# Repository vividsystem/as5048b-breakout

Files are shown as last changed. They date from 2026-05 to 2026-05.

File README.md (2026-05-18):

# AS5048B Breakout Board


> [!NOTE]
> This is a breakout for the AS5048B not AS5048A board i.e. this is a breakout for the I²C version.

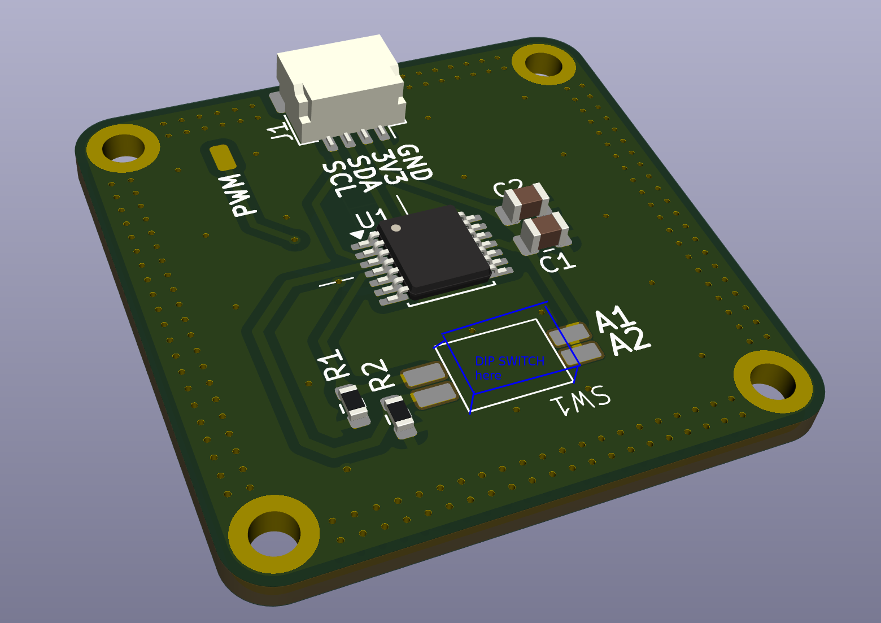
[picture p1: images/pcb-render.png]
PCB Render


## Specs & Features 
- 14bit resolution -> 16384 positions per revolution
- I²C High Speed at 3.4MHz clock frequency
- easy hand-assembly
- JST SM04B-SRSS (SH series) connector for easy connections
(SparkFun Qwiic/Adafruit STEMMA QT/Arduino Modulino compatible)

## Usage
### Choosing the correct magnet
* 6-8mm diameter
* \>= 2.5mm height
* diametric

### Magnet Placement
* 0.5mm to 2.5mm above IC
* magnet and board share same center (displacement of up to 0.25mm ok)

more details [here](https://look.ams-osram.com/m/287d7ad97d1ca22e/original/AS5048-DS000298.pdf)

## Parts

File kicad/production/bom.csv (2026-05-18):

Designator | Footprint | Quantity | Value | LCSC Part #
C1 | 0805 | 1 | 10u | C15850
C2 | 0805 | 1 | 100n | C28233
J1 | JST_SH_SM04B-SRSS-TB_1x04-1MP_P1.00mm_Horizontal | 1 | IIC | C160404
R1, R2 | 0603 | 2 | 10k | C25804
SW1 | EP-02KS DIP 1.27mm | 1 | ADDR SELECT | C54949
U1 | TSSOP-14_4.4x5mm_P0.65mm | 1 | AS5048B | C2655184

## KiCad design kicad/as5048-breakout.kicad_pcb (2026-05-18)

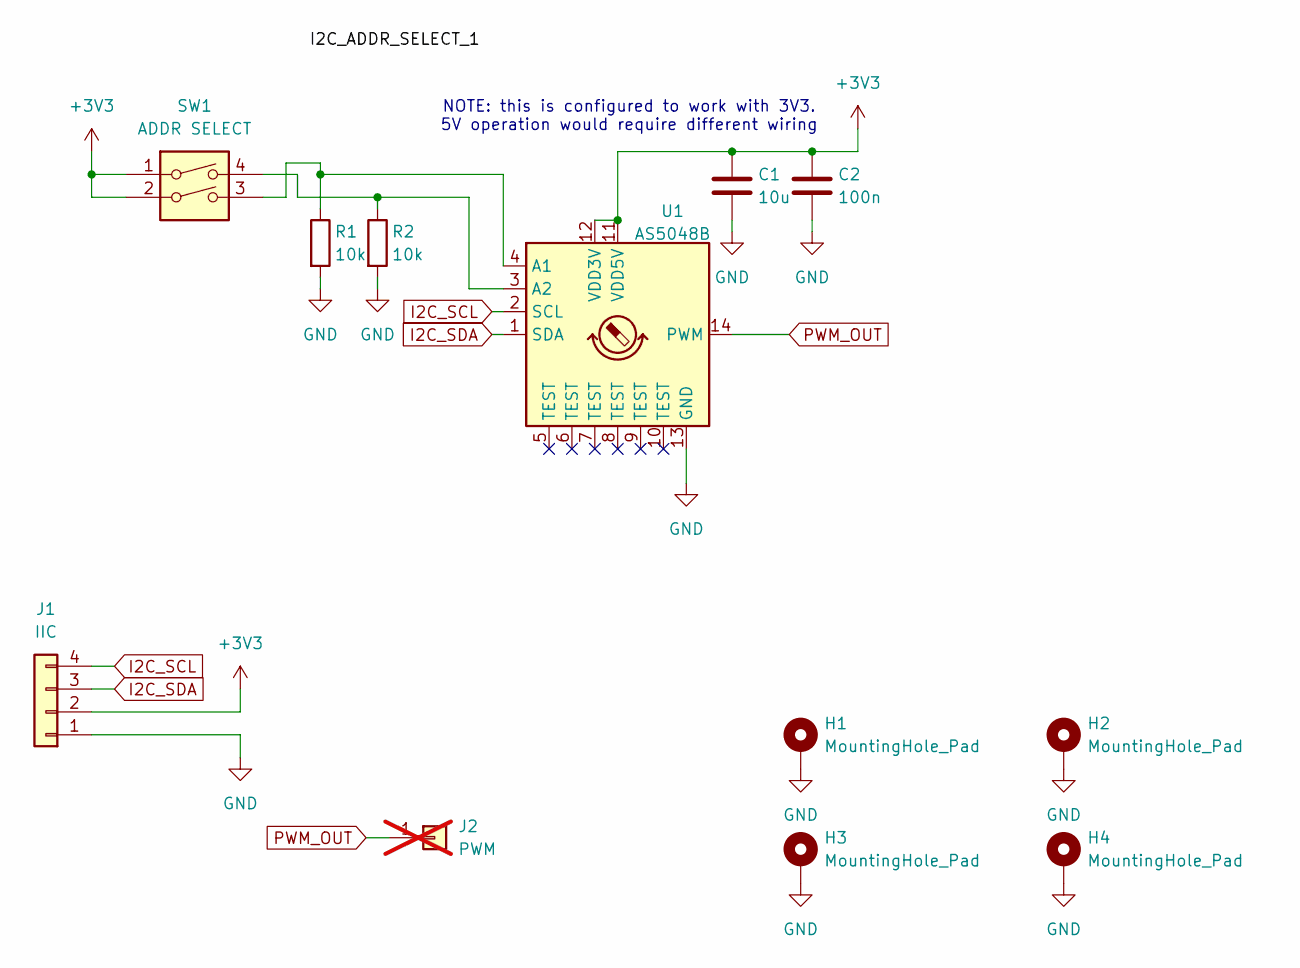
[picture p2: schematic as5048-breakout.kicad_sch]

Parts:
C1: 10u; C_0805_2012Metric; LCSC Part C15850
C2: 100n; C_0805_2012Metric; LCSC Part C28233
H1, H2, H3, H4: MountingHole_Pad; MountingHole_2.2mm_M2_DIN965_Pad
J1: IIC; JST_SH_SM04B-SRSS-TB_1x04-1MP_P1.00mm_Horizontal; LCSC Part C160404
J2: PWM; SolderWirePad_1x01_SMD_1x2mm; not fitted
R1, R2: 10k; R_0603_1608Metric; LCSC Part C25804
SW1: ADDR SELECT; EP-02KS DIP 1.27mm; LCSC Part C54949
U1: AS5048B; TSSOP-14_4.4x5mm_P0.65mm; LCSC Part C2655184

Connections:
+3V3: C1.2, C2.2, J1.2, SW1.1, SW1.2, U1.11 (VDD5V), U1.12 (VDD3V)
GND: C1.1, C2.1, H1.1, H2.1, H3.1, H4.1, J1.1, R1.2, R2.2, U1.13 (GND)
I2C_SCL: J1.4, U1.2 (SCL)
I2C_SDA: J1.3, U1.1 (SDA)
unnamed: R1.1, SW1.3, U1.4 (A1)
unnamed: R2.1, SW1.4, U1.3 (A2)
PWM_OUT: J2.1, U1.14 (PWM)

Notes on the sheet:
NOTE: this is configured to work with 3V3. 5V operation would require different wiring

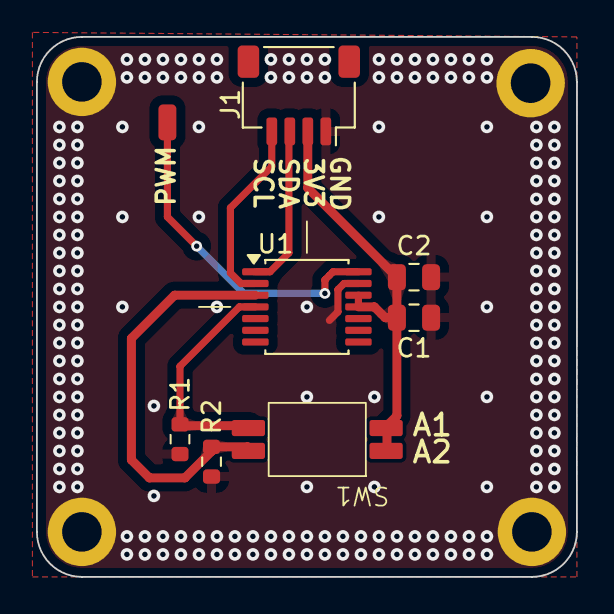
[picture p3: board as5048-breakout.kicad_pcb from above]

Board: 2 copper layers, 30.0 x 30.0 mm, 12 parts (0 on the bottom side), 7 nets.

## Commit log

2026-02-26 fix: bom LCSC part no
    [as5048-breakout.kicad_sch, bom.csv]
2026-02-26 docs: add pcb render image
2026-03-02 finalizing this
    [as5048-breakout.kicad_pcb, bom.csv]
2026-05-18 feat: change pinheader to JST SH 1x4
    with same pinouts as the Adafruit Qwiic or Stemma
    connectors so that they could be used with their boards
    (different pitch connectors used)
    [as5048-breakout.kicad_pcb, as5048-breakout.kicad_sch, bom.csv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]
2026-05-18 docs: add note about connector
2026-05-18 chore: update note to include all vendors using JST SH connectors
